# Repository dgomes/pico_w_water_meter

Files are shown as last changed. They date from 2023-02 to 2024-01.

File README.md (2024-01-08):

# Water Meter Sensor

Monitor your water usage through an energy-efficient IoT device attached to your water provider meter (which happens to have a metal "butterfly wheel) like the JANZ JT400:

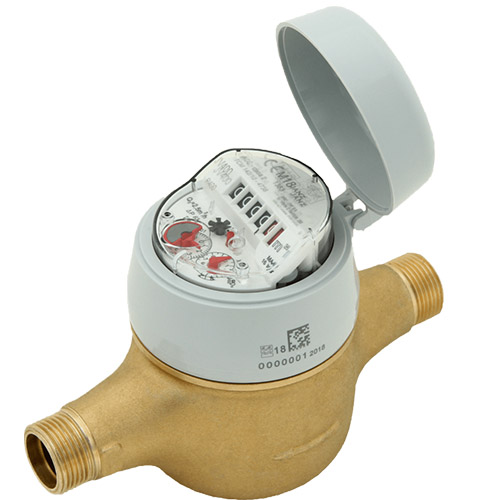
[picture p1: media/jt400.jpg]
Water Meter


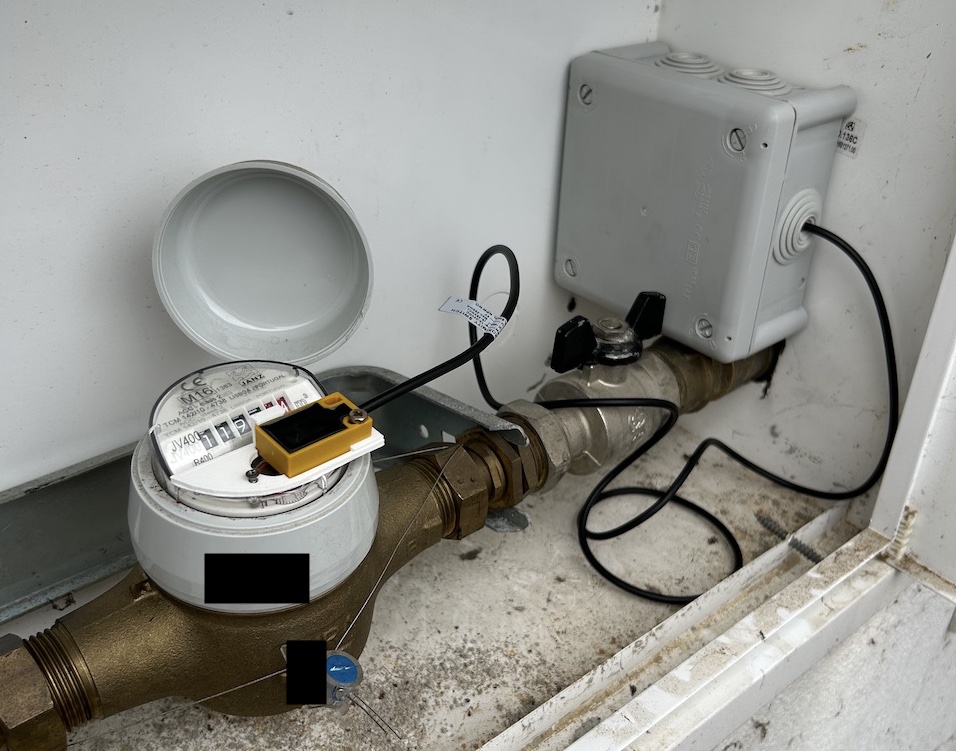
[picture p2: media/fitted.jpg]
Water Meter All in place


This project enables you to monitor the water usage of your household water usage through the use of a DIY water meter sensor built using:

- [Raspberry Pi Pico W](https://www.raspberrypi.com/documentation/microcontrollers/raspberry-pi-pico.html)
- [Inductive Proximity Sensor Detection Switch - TL-W5MC1](https://www.aliexpress.com/item/32973109912.html)
- [TI High-Speed CMOS Logic 14-Stage Binary Counter](https://www.ti.com/lit/ds/symlink/cd54hc4020.pdf)

The RPI Pico W is very flexible in terms of power requirements, but in my case, I use:

- 18650 Battery
- [18650 TP4056 Lithium Battery Charger Module With Protection](https://www.aliexpress.com/item/32930640893.html)
- [Mini Boost Module Step Up Board 5V](https://www.aliexpress.com/item/4000626913742.html) (to power the Inductive Proximity Sensor which states minimum 6V but actually works with 5V)

Just assemble everything :)

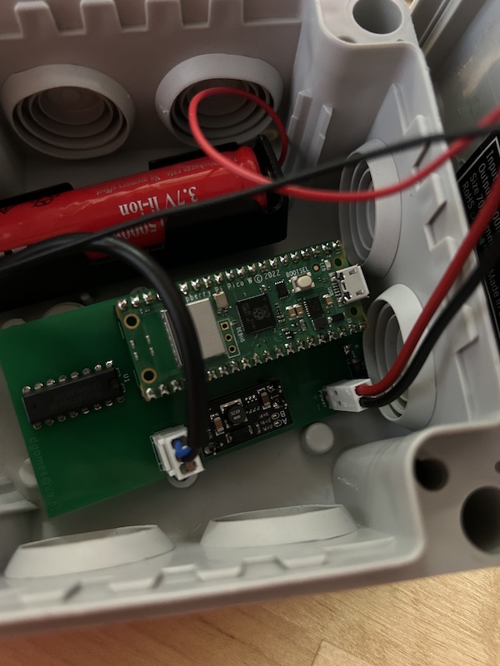
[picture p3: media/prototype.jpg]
Box with PCB and Battery inside Prototype


You can find the PCB source files (KiCAD) in the respective directory. ([PCB files](https://github.com/dgomes/pico_w_water_meter/tree/main/Water%20Meter%20PCB))

I designed a 3D-printed adapter for the Inductive Proximity Sensor to fit the JANZ JT400.  ([3Dadapter](https://github.com/dgomes/pico_w_water_meter/tree/main/3Dadapter))

The RPi Pico W is flashed with a micropython firmware and then you upload the project available in `src`

You must have an MQTT broker (e.g. Mosquitto)

The project automatically integrates with [Home Assistant](https://www.home-assistant.io)

# config.py

You will need to create an additional file called `config.py` that must include the variables:

```python
SSID = "myhome_network"
WIFI_PASSWORD = "blablabla" 

SERVER = "192.168.1.1"  #this is your MQTT Broker Address
USER = None #change this to your MQTT username, else leave None
PASSWORD = None #change this to your MQTT password, else leave None

```

# Powering

- Using a 18650 3.7v battery the sensor can run for 2 weeks
- Using a battery pack of 4 AA batteries the sensor can run for 4 weeks

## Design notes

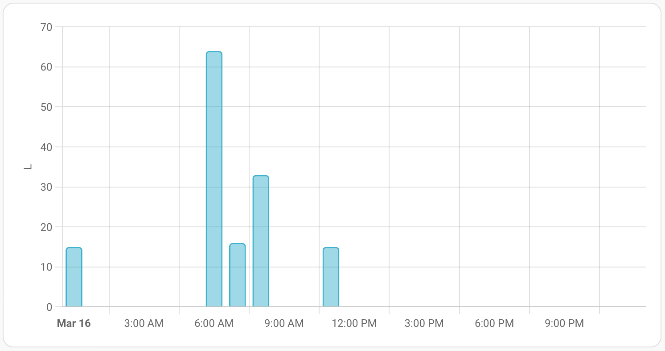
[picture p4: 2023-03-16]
media/Screenshot 2023-03-16 at 12.58.16.png

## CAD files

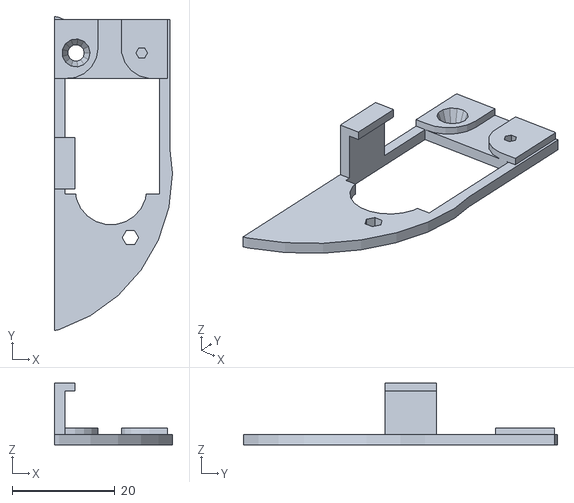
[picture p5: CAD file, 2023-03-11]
3Dadapter/ContadorAgua2.stl
23.0 x 61.2 x 12.0

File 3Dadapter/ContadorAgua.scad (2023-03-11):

difference() {
    union() {
        
        color([1, 0, 0])
        linear_extrude(2)
        difference() {
            translate([-8, -7, 0])
                circle(32);
            translate([12, -10, 0])
                circle(7);
        }
        // Apoios para parafusos
        difference() {
            color([1, 0, 0]) {
                
                translate([-2.5, 17.5, 0]) 
                    minkowski() {
                        cylinder(h=2.5, r=6);
                        cube([6,6,.8]);
                    }
                translate([20, 17.5, 0])
                    minkowski() {
                        cylinder(h=2.5, r=6);
                        cube([6,6,.8]);
                    }
            }
            union() {
                translate([23, 11.5,0])
                    cube([40, 40, 4]);
                translate([0, 23,0])
                    cube([40, 20, 4]);
                }
        }
        //Fechar ponta do sensor no semi circulo
        translate([9, 11, 0])
                cube([14, 12, 2]);

        //Reforço cilindro Externo
        translate([19, -7, 0])
                cube([4.5, 30, 2]);

        // Abraço do sensor
        color([0, 0, 0])
        translate([1, -10, 2])
            cube([4, 10, 10]);
    }
    // Remover resto do cilindro
    translate([-79, -50, -1]) {
        cube([80, 100, 10]);
    }
    
    // Parafusos
    color([1, 0, 0])
    union() {
        translate([5.2,16.5, -0.005])
        cylinder(h=7, r1=1.6, r2=4);
        
        translate([18,16.5, 1])
        cylinder(h=3, r1=1.6, r2=1);
        
        translate([15.8, -19.5, -5])
        cylinder(h=10, r1=1.6, r2=1.6);
    };

    //Corpo do Sensor
    translate([3, -11, -1])
    color([0, 0, 1])
        cube([18.5, 22.5, 11.5]);
}

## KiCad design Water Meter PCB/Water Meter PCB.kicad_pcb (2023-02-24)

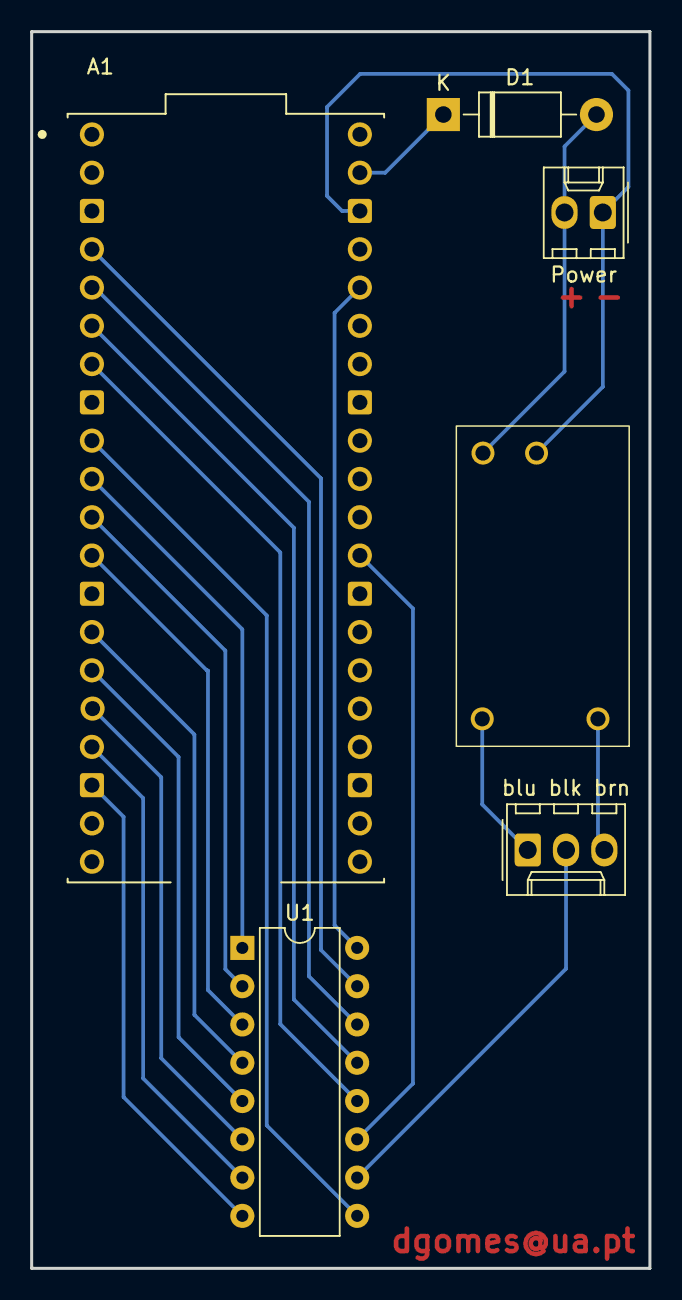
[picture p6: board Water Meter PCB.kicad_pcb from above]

Board: 2 copper layers, 41.0 x 82.1 mm, 6 parts (0 on the bottom side), 21 nets.

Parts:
A1: SC0918; MODULE_SC0918
BS01+1: BS01+
D1: 1N5819; D_DO-41_SOD81_P10.16mm_Horizontal
Power: pos; Molex_KK-254_AE-6410-02A_1x02_P2.54mm_Vertical
U1: 4020; DIP-16_W7.62mm
blu blk brn: TL-W5MC1; Molex_KK-254_AE-6410-03A_1x03_P2.54mm_Vertical

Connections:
unnamed: A1.36 (3V3_OUT), U1.16 (VDD)
unnamed: A1.4 (GP2), U1.15 (Q10)
unnamed: A1.5 (GP3), U1.14 (Q9)
unnamed: A1.6 (GP4), U1.13 (Q7)
unnamed: A1.7 (GP5), U1.12 (Q8)
unnamed: A1.9 (GP6), U1.9 (Q0)
unnamed: A1.10 (GP7), U1.1 (Q11)
unnamed: A1.11 (GP8), U1.2 (Q12)
unnamed: A1.12 (GP9), U1.3 (Q13)
unnamed: A1.14 (GP10), U1.4 (Q5)
unnamed: A1.15 (GP11), U1.5 (Q4)
unnamed: A1.16 (GP12), U1.6 (Q6)
unnamed: A1.17 (GP13), U1.7 (Q3)
unnamed: A1.29 (GP22), U1.11 (Reset)
unnamed: A1.39 (VSYS), D1.1 (K)
unnamed: BS01+1.4 (in_+), D1.2 (A), Power.2
unnamed: A1.38 (GND), BS01+1.3 (in_-), Power.1
unnamed: BS01+1.1 (out_+), blu blk brn.3
unnamed: BS01+1.2 (out_-), blu blk brn.1
unnamed: U1.10 (CLK), blu blk brn.2
unnamed: A1.18 (GND), U1.8 (VSS)

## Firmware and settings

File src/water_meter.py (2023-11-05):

"""Water Meter."""

import json
import logging
import time

import lowpower
import network
import ubinascii
from machine import ADC, Pin, reset, unique_id
from micropython import const
from umqtt.simple import MQTTClient

from config import BSSID, SERVER, SSID, WIFI_PASSWORD, USER, PASSWORD

logging.basicConfig(level=logging.DEBUG)

VERSION = const(1)
MAX_WIFI_RETRIES = const(10)
RESET_VALUE = const(2**13)
MAX_BATTERY = const(5.2)  # 4 x 1.3v - 4xAA NiCM
MIN_BATTERY = const(3.3)  

NAME = "Water Meter"
NAME_SLUG = "water_meter"

CLIENT_ID = ubinascii.hexlify(unique_id())
STATE_TOPIC = f"{NAME_SLUG}/sensor/{NAME_SLUG}_total/state"
TOTAL_TOPIC = f"{NAME_SLUG}/sensor/total_water_usage/state"
BATT_STATE_TOPIC = f"{NAME_SLUG}/sensor/{NAME_SLUG}_battery_level/state"
BATT_VOLTAGE_TOPIC = f"{NAME_SLUG}/sensor/{NAME_SLUG}_voltage/state"
AVAILABILITY_TOPIC = f"{NAME_SLUG}/status"
CMD_TOPIC = f"{NAME_SLUG}/cmd"
DORMANT_PIN_TOPIC = f"{NAME_SLUG}/dormant"

CMD_RESET = b"reset"
CMD_DISCOVERY = b"discovery"

##
##  https://www.ti.com/lit/ds/symlink/cd54hc4020.pd
##
## 1st Column
q12 = Pin(7, Pin.IN, Pin.PULL_DOWN)
q13 = Pin(8, Pin.IN, Pin.PULL_DOWN)
q14 = Pin(9, Pin.IN, Pin.PULL_DOWN)
q6 = Pin(10, Pin.IN, Pin.PULL_DOWN)
q5 = Pin(11, Pin.IN, Pin.PULL_DOWN)
q7 = Pin(12, Pin.IN, Pin.PULL_DOWN)
q4 = Pin(13, Pin.IN, Pin.PULL_DOWN)
# gnd
## 2nd Column
# vcc
q11 = Pin(2, Pin.IN, Pin.PULL_DOWN)
q10 = Pin(3, Pin.IN, Pin.PULL_DOWN)
q8 = Pin(4, Pin.IN, Pin.PULL_DOWN)
q9 = Pin(5, Pin.IN, Pin.PULL_DOWN)
mr = Pin(22, Pin.OUT, value=0)
# cp
q1 = Pin(6, Pin.IN, Pin.PULL_DOWN)


spms = Pin("WL_GPIO1", Pin.OUT)
led = Pin("LED", Pin.OUT)
wlan_pwr = Pin(23, Pin.OUT)
DORMANT_PIN = 11

reset_pin = Pin(21, Pin.IN, Pin.PULL_DOWN)
reset_flag = reset_pin.value()

ha_discovery_flag = False


def ha_discovery(mqtt_client):
    """Send MQTT messages for Home Assistant Discovery."""
    device = {
        "ids": CLIENT_ID,
        "name": NAME,
        "sw": f"dgomes v{VERSION}",
        "mdl": "pico W",
        "mf": "Raspberry Foundation",
    }

    sensors = {
        "water_meter_total": {
            "dev_cla": "water",
            "unit_of_meas": "L",
            "stat_cla": "total_increasing",
            "name": "Total",
            "ic": "mdi:pulse",
            "stat_t": STATE_TOPIC,
            "ent_cat": "diagnostic",
            "uniq_id": "PICOsensorwater_meter_total",
            "dev": device,
            "value_template": "{{ value_json.counter }}",
        },
        "water_meter_battery_level": {
            "dev_cla": "battery",
            "unit_of_meas": "%",
            "name": "Battery Level",
            "stat_t": STATE_TOPIC,
            "frc_upd": "true",
            "uniq_id": "PICOsensorwater_meter_battery_level",
            "dev": device,
            "value_template": "{{ value_json.battery_level }}",
        },
        "water_meter_voltage": {
            "dev_cla": "voltage",
            "stat_cla": "measurement",
            "unit_of_meas": "V",
            "name": "Voltage",
            "stat_t": STATE_TOPIC,
            "ent_cat": "diagnostic",
            "frc_upd": "true",
            "uniq_id": "PICOsensorwater_meter_voltage",
            "dev": device,
            "value_template": "{{ value_json.voltage }}",
        },
        "total_water_usage": {
            "dev_cla": "water",
            "unit_of_meas": "m³",
            "stat_cla": "total_increasing",
            "name": "Total Usage",
            "stat_t": STATE_TOPIC,
            "uniq_id": "PICOsensortotal_water_usage",
            "dev": device,
            "value_template": "{{ value_json.total }}",
        },
    }
    logging.info("HA Discovery")
    blink_n_times(3, period=0.2)
    for name, sensor in sensors.items():
        logging.debug("%s: %s", name, json.dumps(sensor))
        mqtt_client.publish(
            f"homeassistant/sensor/water_meter/{name}/config".encode(),
            json.dumps(sensor).encode(),
            True,
            1,
        )


def blink_n_times(n: int, period: float = 0.5):
    """Blink LED."""
    for _ in range(2 * n):
        # toggle LED
        led(not led())
        time.sleep(period)


def wait_for_wifi(wlan):
    """Wait for connectiong to Wifi."""
    wlan.connect(SSID, WIFI_PASSWORD)  # , bssid=BSSID)

    # Wait for connect or fail
    max_wait = MAX_WIFI_RETRIES
    while max_wait > 0:
        if wlan.status() < 0 or wlan.status() >= 3:  # cyw43-driver/src/cyw43.h:
            break
        max_wait -= 1
        blink_n_times(2)

    if wlan.status() != 3:
        raise Exception("not connected")
    logging.debug("Connected!")


def read_counter():
    """Read cd54hc4020."""
    counter = (
        (q14.value() << 13)
        | (q13.value() << 12)
        | (q12.value() << 11)
        | (q11.value() << 10)
        | (q10.value() << 9)
        | (q9.value() << 8)
        | (q8.value() << 7)
        | (q7.value() << 6)
        | (q6.value() << 5)
        | (q5.value() << 4)
        | (q4.value() << 3)
        | q1.value()
    )
    logging.debug("Meter: %s Liter", counter)
    return counter


def mqtt_callback(topic: str, msg: str):
    """MQTT Callback handler."""
    global reset_flag, ha_discovery_flag, DORMANT_PIN
    logging.debug((topic, msg))
    if topic == CMD_TOPIC.encode():
        if msg == CMD_RESET:
            reset_flag = True
        if msg == CMD_DISCOVERY:
            ha_discovery_flag = True
    elif topic == DORMANT_PIN_TOPIC.encode():
        DORMANT_PIN = int(msg)


def measure_vsys():
    """Retrieve VSYS."""
    # https://forums.raspberrypi.com/viewtopic.php?p=2062568&sid=3b63feda7bb0465d6234551dd5286da2#p2062568
    Pin(25, Pin.OUT, value=1)
    Pin(29, Pin.IN, pull=None)
    reading = ADC(3).read_u16() * 9.9 / 2**16
    logging.debug("VSYS: %s Volt", reading)

    Pin(25, Pin.OUT, value=0, pull=Pin.PULL_DOWN)
    Pin(29, Pin.ALT, pull=Pin.PULL_DOWN, alt=7)
    return reading


def main():
    """Fake a Main Loop through a reset at the end."""
    # Inital setup
    start = time.ticks_ms()
    global reset_flag, ha_discovery_flag

    # Measure battery before anything wifi related
    battery = measure_vsys()

    # Connect to MQTT Server
    led.on()
    wlan = network.WLAN(network.STA_IF)
    wlan.active(True)
    try:
        wait_for_wifi(wlan)

        mqtt_client = MQTTClient(CLIENT_ID, SERVER, user=USER, password=PASSWORD, keepalive=30)
        mqtt_client.connect(clean_session=False)
        mqtt_client.set_callback(mqtt_callback)
        mqtt_client.subscribe(CMD_TOPIC.encode())
        mqtt_client.publish(AVAILABILITY_TOPIC.encode(), "online", True, 1)

        # read the meter
        meter = read_counter()
        if meter < 16 or ha_discovery_flag:
            ha_discovery(mqtt_client)
            ha_discovery_flag = False
        state = {
            "counter": meter,
            "battery_level": int(100 * (battery - MIN_BATTERY) / (MAX_BATTERY - MIN_BATTERY)),
            "voltage": round(battery, 2),
            "total": meter * 0.001,
            "ms_elapsed": time.ticks_diff(start, time.ticks_ms())
        }
        # Publish meter information
        mqtt_client.publish(STATE_TOPIC.encode(), json.dumps(state).encode(), False, 1)

        # Before sleeping again
        mqtt_client.check_msg()
        mqtt_client.publish(AVAILABILITY_TOPIC.encode(), "offline", True, 1)

        logging.debug("Disconnect")
        mqtt_client.disconnect()
        wlan.disconnect()
    except Exception as e:
        logging.error(e)
        reset()

    led.off()
    wlan.active(False)
    wlan.deinit()
    time.sleep_us(100)
    wlan_pwr.low()

    if reset_flag or meter >= RESET_VALUE:
        mr.on()
        logging.info("RESET METER")
        time.sleep_us(100)
        reset_flag = False
        mr.off()

    spms.low()
    lowpower.dormant_with_modes({DORMANT_PIN: (lowpower.EDGE_LOW | lowpower.EDGE_HIGH)})

    reset()


if __name__ == "__main__":
    main()

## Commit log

2023-02-24 Initial Version
    [Water Meter PCB.kicad_pcb, Water Meter PCB.kicad_sch]
2023-03-11 current deployed version
    [ContadorAgua.scad, ContadorAgua2.stl]
